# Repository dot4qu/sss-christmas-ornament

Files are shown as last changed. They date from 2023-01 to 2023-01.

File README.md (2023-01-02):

# sss-christmas-ornament

Photo of donut ornament on a christmas tree

A donut-shaped christmas ornament to share with friends and family in 2022. Hardware designed in KiCad, firmware written with Arduino framework and flashed over AVR UPDI interface.

More information in the writeup [here](https://brian.team/art/ornament-2022/).

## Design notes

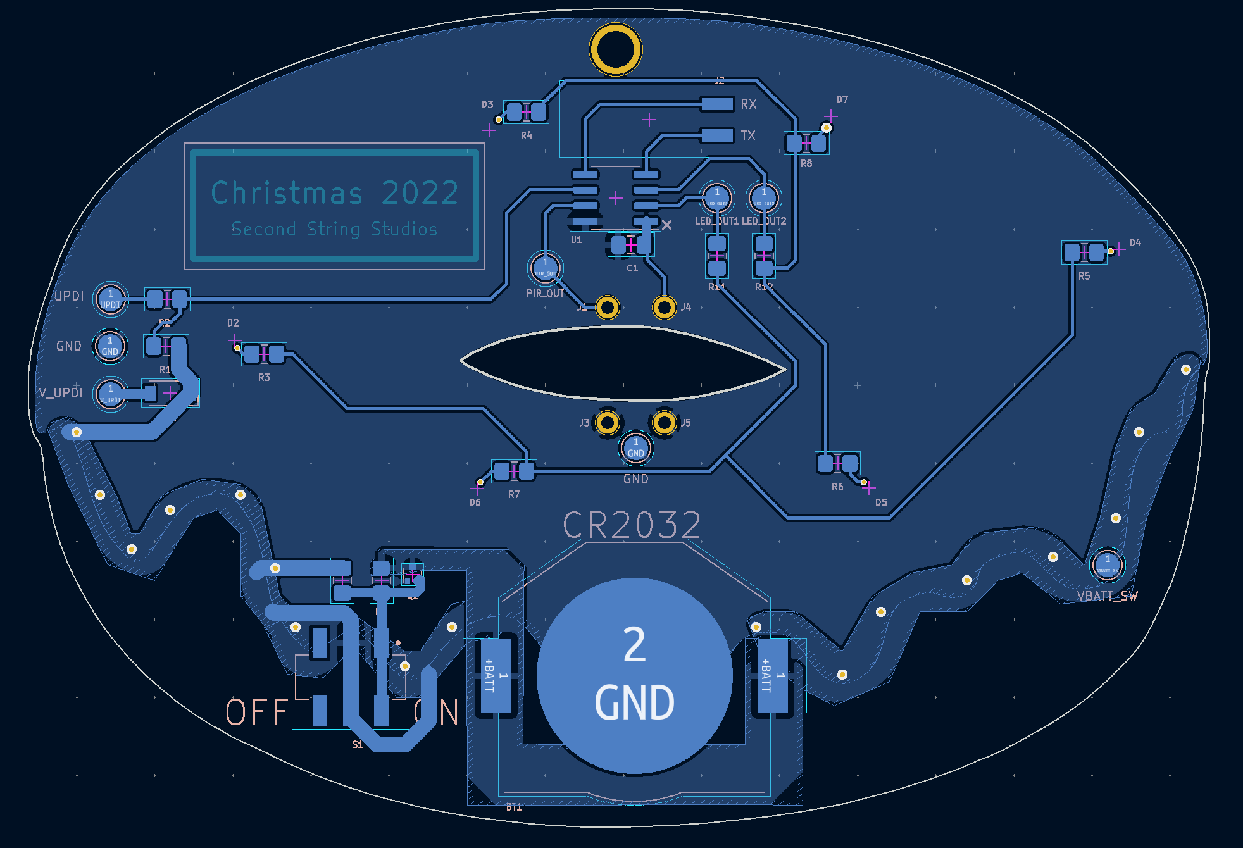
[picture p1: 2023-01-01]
sss_ornament_2022_pcb_back.png

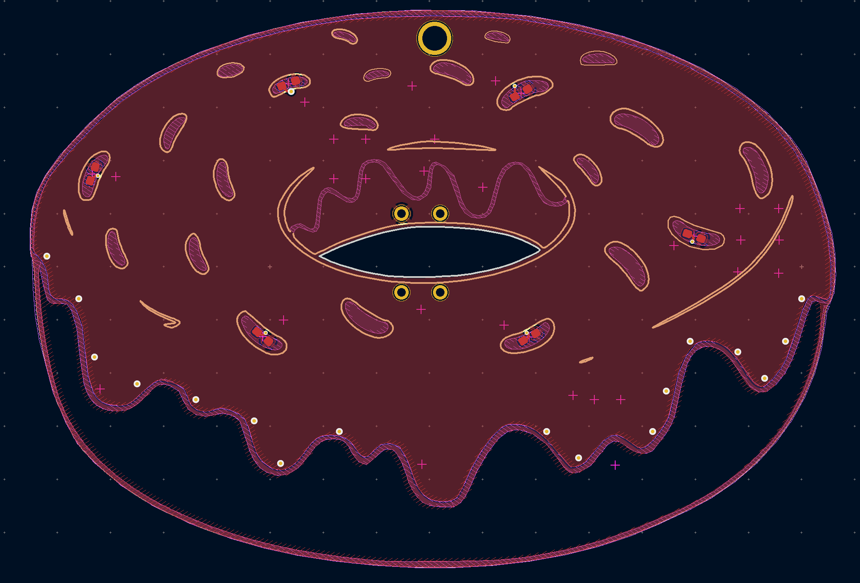
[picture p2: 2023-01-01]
sss_ornament_2022_pcb_front.png

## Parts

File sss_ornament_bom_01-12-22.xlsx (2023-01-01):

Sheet: sss_ornament_bom_edited
Designator | Package | Quantity | Designation | Supplier and ref
D7,D5,D2,D6,D4,D3 | LED_0603_1608Metric_Pad1.05x0.95mm_HandSolder | 6 | LED | https://www.digikey.de/en/products/detail/würth-elektronik/150060VS75000/4489906
R2 | R_0805_2012Metric_Pad1.20x1.40mm_HandSolder | 1 | 470 | https://www.digikey.de/en/products/detail/yageo/RC0805JR-07470RL/728333
R12,R11,R1,R9 | R_0805_2012Metric_Pad1.20x1.40mm_HandSolder | 4 | 0 | https://www.digikey.de/en/products/detail/stackpole-electronics-inc/RMCF0805ZT0R00/1756901
R8,R7,R6,R4,R3,R5 | R_0805_2012Metric_Pad1.20x1.40mm_HandSolder | 6 | 8.2k | https://www.digikey.de/en/products/detail/yageo/RC0805FR-078K2L/728147
R10 | R_0805_2012Metric_Pad1.20x1.40mm_HandSolder | 1 | 10k | https://www.digikey.de/en/products/detail/stackpole-electronics-inc/RNCP0805FTD10K0/2240262
C1 | C_0805_2012Metric_Pad1.18x1.45mm_HandSolder | 1 | 0.1uF | https://www.digikey.de/en/products/detail/samsung-electro-mechanics/CL21B104KBCNNNC/3886661
Q2 | SOT-723 | 1 | Q_PMOS_DGS | https://www.digikey.de/en/products/detail/toshiba-semiconductor-and-storage/SSM3J35AMFV-L3F/8543433
D1 | D_SOD-123 | 1 | 1N4148W | https://www.digikey.de/en/products/detail/smc-diode-solutions/1N4148W/6022450
U1 | SOIC-8_3.9x4.9mm_P1.27mm | 1 | ATtiny412-SS | https://www.digikey.de/en/products/detail/microchip-technology/ATTINY412-SSN/9947540
BT1 | BatteryHolder_AdamTech_BH-67D-5_1x2032 | 1 | CR2032 | https://www.digikey.de/en/products/detail/adam-tech/BH-67D-5/13537750
S1 | SW_JS202011SCQN | 1 | JS202011SCQN | https://www.digikey.de/en/products/detail/c-k/JS202011SCQN/2094299

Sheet: sss_ornament_bom_generated
Id | Designator | Package | Quantity | Designation | Supplier and ref
1 | D7,D5,D2,D6,D4,D3 | LED_0603_1608Metric_Pad1.05x0.95mm_HandSolder | 6 | LED
2 | R2 | R_0805_2012Metric_Pad1.20x1.40mm_HandSolder | 1 | 470
3 | J4 | PinHeader_1x01_P2.54mm_Vertical | 1 | V_PIR
4 | TP1 | TestPoint_Pad_D2.0mm | 1 | PIR_OUT
5 | TP6 | TestPoint_Pad_D2.0mm | 1 | V_UPDI
6 | J2 | Harwin_M20-89003xx_1x02_P2.54mm_Horizontal | 1 | Conn_01x02_Male
7 | R12,R11,R1,R9 | R_0805_2012Metric_Pad1.20x1.40mm_HandSolder | 4 | 0
8 | TP4 | TestPoint_Pad_D2.0mm | 1 | LED_OUT2
9 | R8,R7,R6,R4,R3,R5 | R_0805_2012Metric_Pad1.20x1.40mm_HandSolder | 6 | 8.2k
10 | J1 | PinHeader_1x01_P2.54mm_Vertical | 1 | Conn_01x01
11 | R10 | R_0805_2012Metric_Pad1.20x1.40mm_HandSolder | 1 | 10k
12 | TP3 | TestPoint_Pad_D2.0mm | 1 | LED_OUT1
13 | TP8,TP5 | TestPoint_Pad_D2.0mm | 2 | GND
14 | C1 | C_0805_2012Metric_Pad1.18x1.45mm_HandSolder | 1 | 0.1uF
15 | TP2 | TestPoint_Pad_D2.0mm | 1 | VBATT_SW
16 | TP7 | TestPoint_Pad_D2.0mm | 1 | UPDI
17 | Q2 | SOT-723 | 1 | Q_PMOS_DGS
18 | D1 | D_SOD-123 | 1 | 1N4148W
19 | J3 | PinHeader_1x01_P2.54mm_Vertical | 1 | GND
20 | J5 | PinHeader_1x01_P2.54mm_Vertical | 1 | PIR_TIME
21 | U1 | SOIC-8_3.9x4.9mm_P1.27mm | 1 | ATtiny412-SS
22 | BT1 | BatteryHolder_AdamTech_BH-67D-5_1x2032 | 1 | CR2032
23 | S1 | SW_JS202011SCQN | 1 | JS202011SCQN

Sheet: part tracking
name | part link | datasheet link
battery clip | https://www.digikey.de/en/products/detail/adam-tech/BH-67D-5/13537750 | https://app.adam-tech.com/products/download/data_sheet/196975/bh-67d-5-data-sheet.pdf
mini PIR | https://www.digikey.de/en/products/detail/adafruit-industries-llc/4667/13175529 | https://cdn-shop.adafruit.com/product-files/4667/4667_C15116.pdf | https://www.adafruit.com/product/4667#technical-details
slide switch | https://www.digikey.de/en/products/detail/c-k/JS202011SCQN/2094299 | https://www.ckswitches.com/media/1422/js.pdf
led fet |  | https://www.digikey.de/en/products/filter/transistors-fets-mosfets-arrays/289
rpp p fet | https://www.digikey.de/en/products/detail/toshiba-semiconductor-and-storage/SSM3J35AMFV-L3F/8543433
v updi diode | https://www.digikey.de/en/products/detail/smc-diode-solutions/1N4148W/6022450

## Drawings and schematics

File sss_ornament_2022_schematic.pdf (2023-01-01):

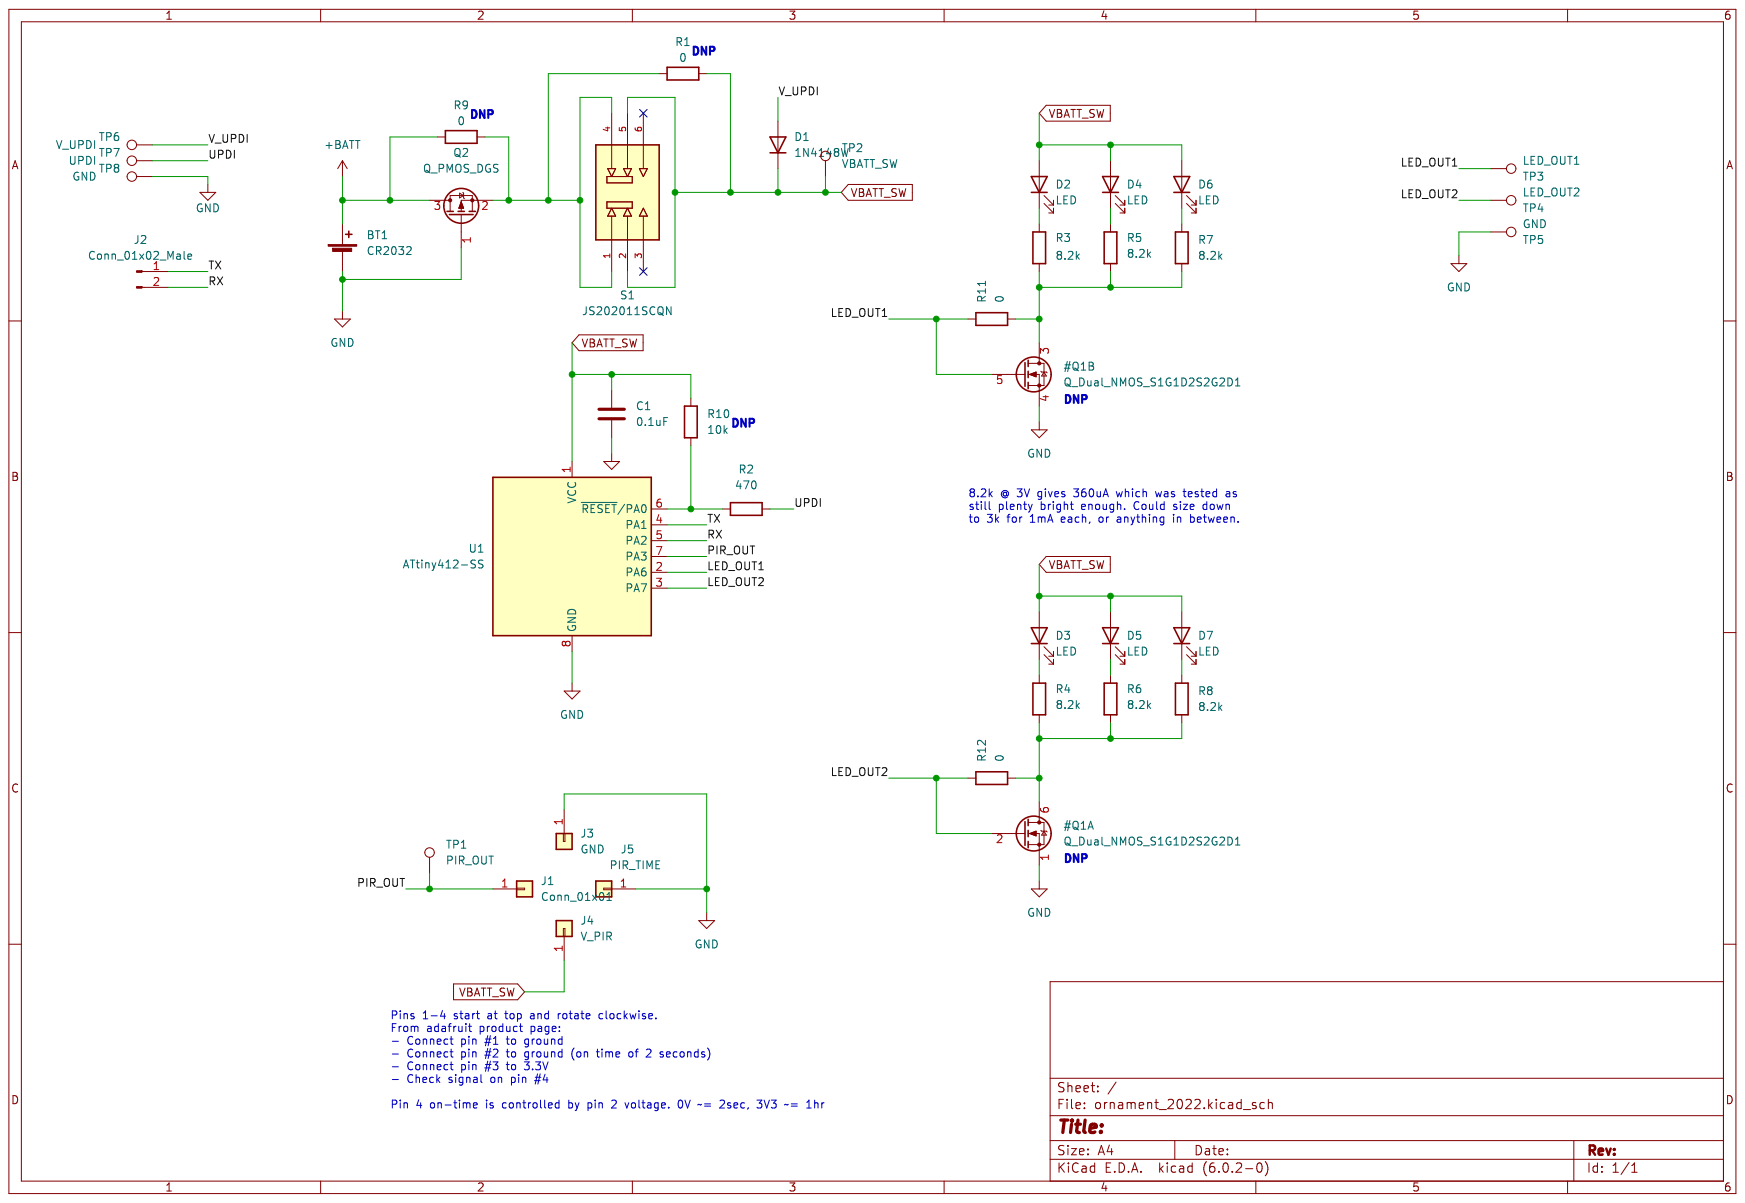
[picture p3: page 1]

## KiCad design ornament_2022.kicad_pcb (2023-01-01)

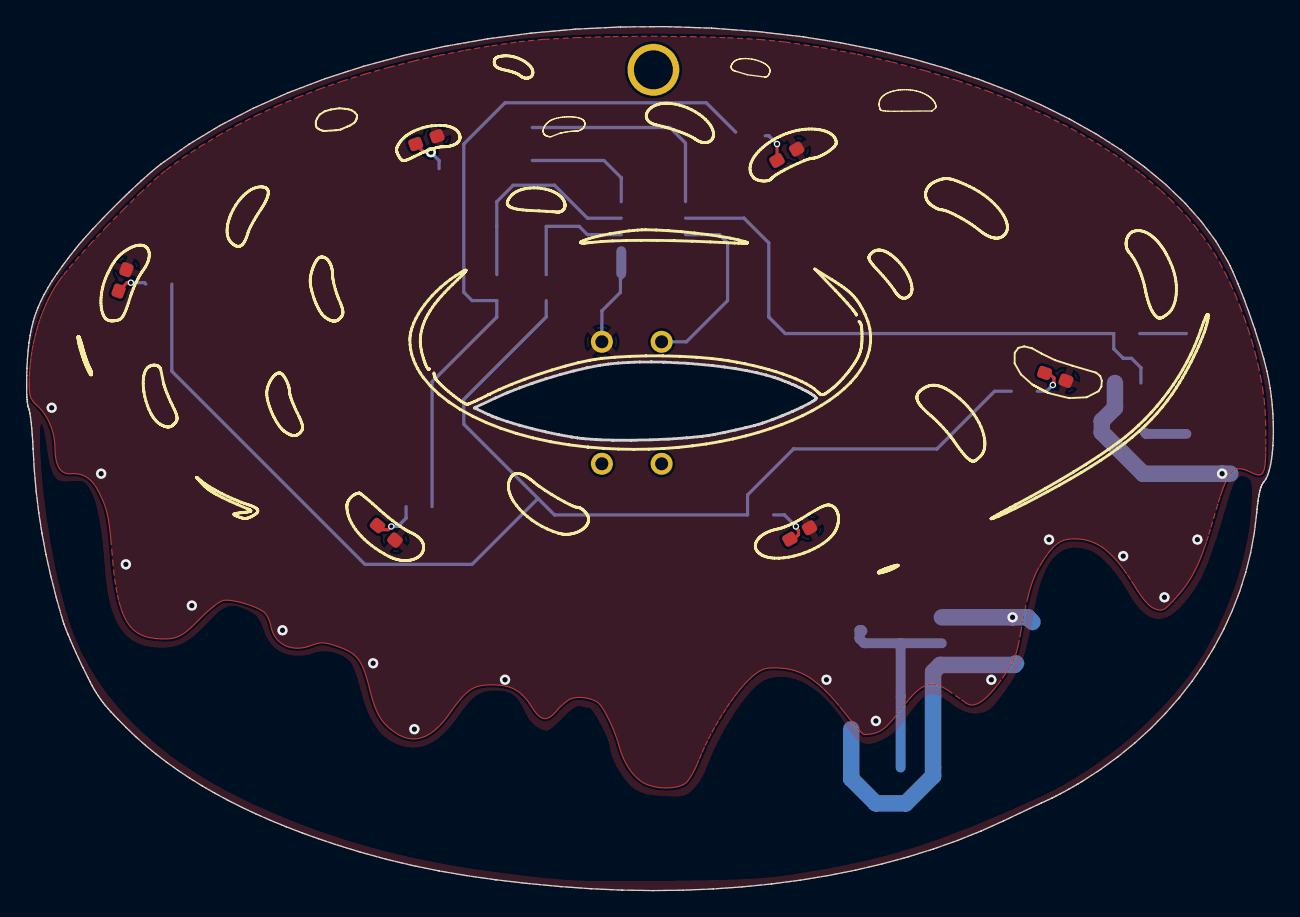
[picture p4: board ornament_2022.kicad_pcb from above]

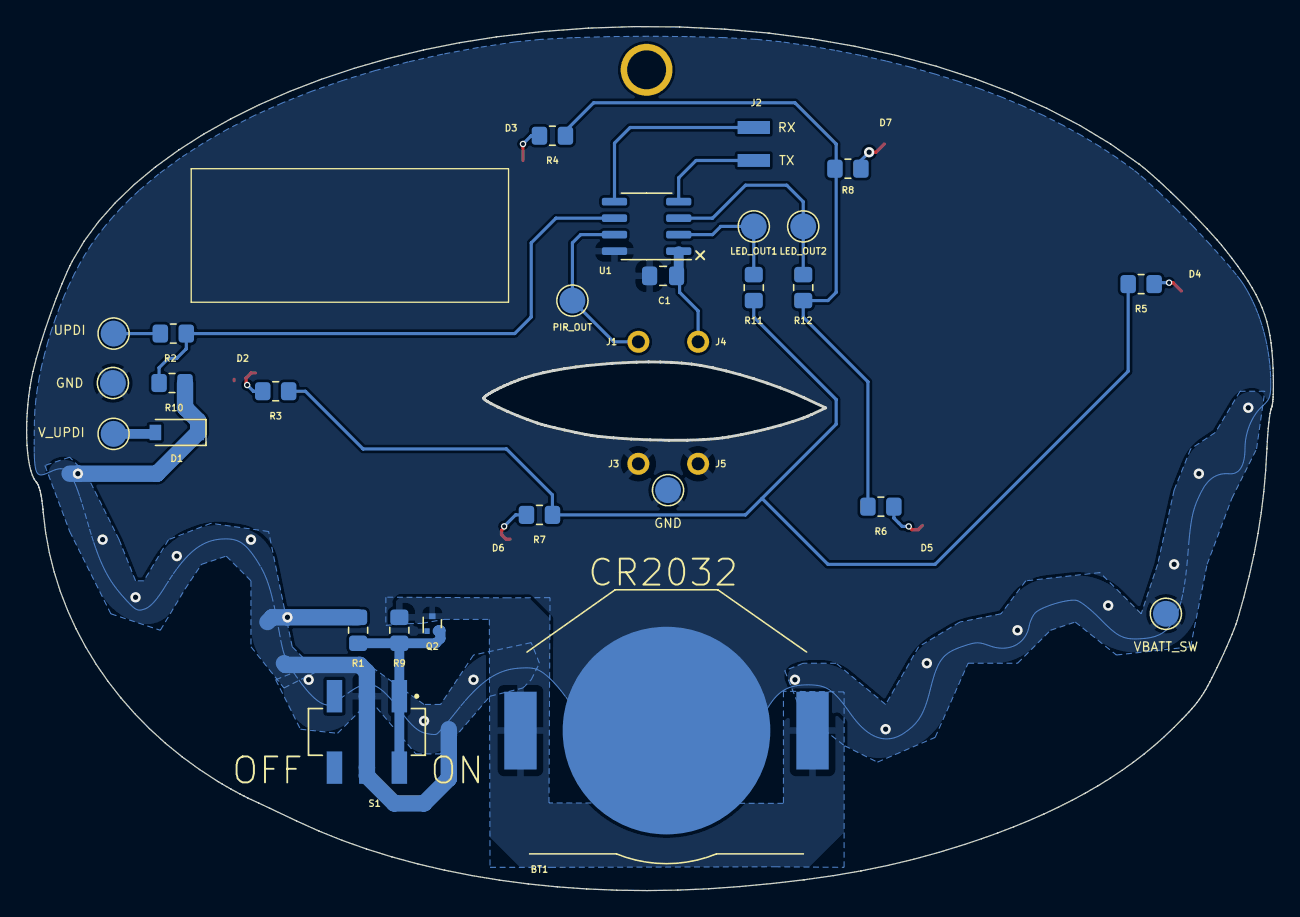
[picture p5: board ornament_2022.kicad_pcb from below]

Board: 2 copper layers, 96.1 x 66.6 mm, 37 parts (31 on the bottom side), 20 nets.

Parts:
BT1: CR2032; BatteryHolder_AdamTech_BH-67D-5_1x2032
C1: 0.1uF; C_0805_2012Metric_Pad1.18x1.45mm_HandSolder
D1: 1N4148W; D_SOD-123
D2, D3, D4, D5, D6, D7: LED; LED_0603_1608Metric_Pad1.05x0.95mm_HandSolder
J1: Conn_01x01; PinHeader_1x01_P2.54mm_Vertical
J2: Conn_01x02_Male; Harwin_M20-89003xx_1x02_P2.54mm_Horizontal
J3: GND; PinHeader_1x01_P2.54mm_Vertical
J4: V_PIR; PinHeader_1x01_P2.54mm_Vertical
J5: PIR_TIME; PinHeader_1x01_P2.54mm_Vertical
Q2: Q_PMOS_DGS; SOT-723
R1, R9, R11, R12: 0; R_0805_2012Metric_Pad1.20x1.40mm_HandSolder
R2: 470; R_0805_2012Metric_Pad1.20x1.40mm_HandSolder
R3, R4, R5, R6, R7, R8: 8.2k; R_0805_2012Metric_Pad1.20x1.40mm_HandSolder
R10: 10k; R_0805_2012Metric_Pad1.20x1.40mm_HandSolder
S1: JS202011SCQN; SW_JS202011SCQN
TP1: PIR_OUT; TestPoint_Pad_D2.0mm
TP2: VBATT_SW; TestPoint_Pad_D2.0mm
TP3: LED_OUT1; TestPoint_Pad_D2.0mm
TP4: LED_OUT2; TestPoint_Pad_D2.0mm
TP5, TP8: GND; TestPoint_Pad_D2.0mm
TP6: V_UPDI; TestPoint_Pad_D2.0mm
TP7: UPDI; TestPoint_Pad_D2.0mm
U1: ATtiny412-SS; SOIC-8_3.9x4.9mm_P1.27mm

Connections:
+BATT: BT1.1 (+), Q2.3 (D), R9.1
/LED_OUT1: R11.1, TP3.1, U1.2 (PA6)
/LED_OUT2: R12.1, TP4.1, U1.3 (PA7)
/PIR_OUT: J1.1, TP1.1, U1.7 (PA3)
/RX: J2.2, U1.5 (PA2)
/TX: J2.1, U1.4 (PA1)
/UPDI: R2.2, TP7.1
/V_UPDI: D1.2 (A), TP6.1
GND: BT1.2 (-), C1.2, J3.1, J5.1, Q2.1 (G), TP5.1, TP8.1, U1.8 (GND)
unnamed: D2.1 (K), R3.1
unnamed: D3.1 (K), R4.1
unnamed: D4.1 (K), R5.1
unnamed: D5.1 (K), R6.1
unnamed: D6.1 (K), R7.1
unnamed: D7.1 (K), R8.1
unnamed: Q2.2 (S), R1.1, R9.2, S1.1, S1.4
unnamed: R2.1, R10.1, U1.6 (~RESET/PA0)
unnamed: R3.2, R5.2, R7.2, R11.2
unnamed: R4.2, R6.2, R8.2, R12.2
VBATT_SW: C1.1, D1.1 (K), D2.2 (A), D3.2 (A), D4.2 (A), D5.2 (A), D6.2 (A), D7.2 (A), J4.1, R1.2, R10.2, S1.2, S1.5, TP2.1, U1.1 (VCC)

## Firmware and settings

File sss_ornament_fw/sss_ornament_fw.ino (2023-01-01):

#include <avr/sleep.h>

#define LED0_OUT PIN_PA6
#define LED1_OUT PIN_PA7
#define PIR_IN PIN_PA3

#define SLEEP_TIMEOUT_MIN (30)
#define SLEEP_TIMEOUT_MS (1000UL * 60 * SLEEP_TIMEOUT_MIN)

#define LAST_DISPLAYED_MODE_EEPROM_ADDR (0x00)

enum led_mode_t {
  LED_MODE_ALTERNATE_FLASH = 0x00,
  LED_MODE_ALTERNATE_FADE,
  LED_MODE_TRIPLE_FLASH,
  LED_MODE_COUNT,
};

bool success;
volatile uint32_t start_ms;
led_mode_t mode;
uint8_t triple_flash_pin;

#if F_CPU != 1000000
#error Must burn bootloader for 1MHz operation!
#endif

uint16_t normalized_fade_values[101];

ISR(PORTA_PORT_vect) {
  PORTA.INTFLAGS = 0xFF;

  // Refresh start time every time PIR triggers. millis doesn't increment in an ISR but we don't
  // care, just refresh to the most recent time. It's also fast enough and ISR safe to do here.
  start_ms = millis();
}

//EMPTY_INTERRUPT(PORTA_PORT_vect);

void gpio_set(uint8_t pin) {
  digitalWrite(pin, HIGH);
//  if (pin == LED0_OUT) {
//    TCD0.CTRLD &= ~TCD_CMPAVAL_gm;
//  } else if (pin == LED1_OUT) {
//    TCD0.CTRLD &= ~TCD_CMPBVAL_gm;
//  }  
}

void gpio_clr(uint8_t pin) {
  digitalWrite(pin, LOW);
//if (pin == LED0_OUT) {
//    TCD0.CTRLD |= TCD_CMPAVAL_gm;
//  } else if (pin == LED1_OUT) {
//    TCD0.CTRLD |= TCD_CMPBVAL_gm;
//  }
}

void gpio_toggle(uint8_t pin) {
  digitalWrite(pin, !digitalRead(pin));
//  if (pin == LED0_OUT) {
//    TCD0.CTRLD ^= TCD_CMPAVAL_gm;
//  } else if (pin == LED1_OUT) {
//    TCD0.CTRLD ^= TCD_CMPBVAL_gm;
//  }
}

void pwm_timer_init(void) {
    // Enable-protected reg must have 0 written to enable bit before any other bits can be changed, and it defaults to
    // enabled on startup
    TCD0.CTRLA &= ~TCD_ENABLE_bm;

    // Don't need overlapping PWM signals so just do oneramp
    TCD0.CTRLB = TCD_WGMODE_ONERAMP_gc;

    // Disable all input control
    TCD0.INPUTCTRLA = TCD_INPUTMODE_NONE_gc;
    TCD0.INPUTCTRLB = TCD_INPUTMODE_NONE_gc;

    // We will always start high with A output and end high with B output. The clear for A and
    // set for B values are what are adjusted based on desired duty cycle. EVERYTHING is cleared at CMPBCLR, therefore
    // you can't have both pwm signals start at 0 and end at arbitrary times. You have to offset B so it's pwm
    // cycle always ends at 0xFFF, then adjust the start time. That way you can overlap outputs all the way to
    // CMPASET=0,CMPACLR=0xFFE and CMPBSET=0x1,CMPBCLR=0xFFF.
    TCD0.CMPASET = 0x000;
    TCD0.CMPBCLR = 0xFFF;

    TCD0.CMPACLR = 0x000;
    TCD0.CMPBSET = 0x801;
    // System 20mhz clock w/ largest prescaler possible of 32 but no synchronization prescaler. Must be done as last
    // operation before starting timer with ENABLE bit
    // NOTE :: DEFAULT TIMER FOR MILLIS/MICROS FUNCTIONS ON 1-SERIES ATTINIES IS TCD. YOU MUST CHANGE THIS TO TCB IN
    // ARDUINO PORT SETTINGS
    TCD0.CTRLA = TCD_CLKSEL_SYSCLK_gc | TCD_CNTPRES_DIV4_gc | TCD_SYNCPRES_DIV1_gc;
}

void pwm_timer_start(void) {
  TCD0.CTRLC &= ~TCD_CMPOVR_bm;
    
  // Enable WOA and WOB (don't need C and D). Since FAULTCTRL reg is write protected we need to make it editable in
  // CCP reg. Must be done in start func because we can't take over output pins in stop func unless we disable them in FAULTCTRL.
  CPU_CCP        = CCP_IOREG_gc;
  TCD0.FAULTCTRL = TCD_CMPAEN_bm | TCD_CMPBEN_bm;
  
  while (!(TCD0.STATUS & TCD_ENRDY_bm)) {
      ;
  }

  TCD0.CTRLA |= TCD_ENABLE_bm;
}

void pwm_timer_stop(void) {
//  // Enable-protected reg must have 0 written to enable bit before any other bits can be changed,
//  // apparently for the FULL TCD0 reg set (including FAULTCTRL below);
//  TCD0.CTRLA &= ~TCD_ENABLE_bm;
//    
//  // Must disable the WOA/B outputs as well, otherwise we can't write to them still
//  CPU_CCP        = CCP_IOREG_gc;
//  TCD0.FAULTCTRL &= ~TCD_CMPAEN_bm;
////  CPU_CCP        = CCP_IOREG_gc;
////  TCD0.FAULTCTRL &= ~TCD_CMPBEN_bm;

//  TCD0.CTRLA &= ~TCD_ENABLE_bm;
  
  TCD0.CTRLC |= TCD_CMPOVR_bm;
}

void pwm_timer_sync(void) {
    TCD0.CTRLE = TCD_SYNCEOC_bm;
}

bool set_pwm_duty_cycle(uint8_t led_group, uint8_t duty_cycle) {
  if (led_group != LED0_OUT && led_group != LED1_OUT) {
    return false;
  }
  
  if (duty_cycle > 100) {
    return false;
  }

  if (led_group == LED0_OUT) {
    TCD0.CMPACLR = normalized_fade_values[duty_cycle];
  } else if (led_group == LED1_OUT) {
    TCD0.CMPBSET = 0xFFF - normalized_fade_values[duty_cycle];
  }

  return true;
}

void deep_sleep() {
  // Turn off all LEDs before sleeping
  gpio_set(LED0_OUT);
  gpio_set(LED1_OUT);
  
  sleep_enable();
  set_sleep_mode(SLEEP_MODE_STANDBY);
  sleep_cpu();

  // Disable once (if) we wake back up and refresh sleep timer
  start_ms = millis();
  sleep_disable();
}

void eeprom_get_byte(uint8_t eeprom_byte_offset, uint8_t *val) {
  memcpy(val, (uint8_t *)(EEPROM_START + eeprom_byte_offset), 1);
}

void eeprom_save_byte(uint8_t eeprom_byte_offset, uint8_t val) {
  while (NVMCTRL.STATUS & NVMCTRL_EEBUSY_bm);
    
  NVMCTRL.ADDR = EEPROM_START;
    
  *(uint8_t *)(EEPROM_START + eeprom_byte_offset) = val;
  
  CPU_CCP = CCP_SPM_gc;
  NVMCTRL.CTRLA = NVMCTRL_CMD_PAGEERASEWRITE_gc;
}

void setup(){
  success = false;
  
  pinMode(LED0_OUT, OUTPUT);
  pinMode(LED1_OUT, OUTPUT);

  uint8_t last_displayed_mode = 0x00;
  eeprom_get_byte(LAST_DISPLAYED_MODE_EEPROM_ADDR, &last_displayed_mode);

  // Increment last displayed and set mode, resetting to zero if we were on last mode. Default eeprom state of 0xFF also
  // handled by increment automatically rolling over to 0x00. Save for next boot, then continue normal operation
  last_displayed_mode++;
  if (last_displayed_mode >= LED_MODE_COUNT) {
    mode = (led_mode_t)0x00;
  } else {
    mode = (led_mode_t)last_displayed_mode;
  }
  eeprom_save_byte(LAST_DISPLAYED_MODE_EEPROM_ADDR, mode);

  // Startup sequence to differentiate reboot
  for (int i = 0; i < 8; i++) {
      digitalWrite(LED0_OUT, HIGH);
      digitalWrite(LED1_OUT, HIGH);
      delay(100);
      digitalWrite(LED0_OUT, LOW);
      digitalWrite(LED1_OUT, LOW);
      delay(100);
  }
  delay(500);

  if (mode == LED_MODE_ALTERNATE_FADE) {
    // Mapping 1-99 directly to 1-4094 for PWM duty value is very skewed w/ human eye towards brighter, so fade
    // is quick drop to zero then seemingly a long full bright time. The mapping ratio of 1 count on former scale
    // to 10-bit scale is ~41, so slowly scale the incremement value each time by the index / 2. Once incremement
    // value reaches standard mapped step of 41, just keep it there for the remaining normalized values.
    float mult = 0.5;
    int normalized_val;
    int factor;
    for (int i = 1; i < 99; i++) {
      factor = (int)(i * mult);
      if (factor < 41) {
        normalized_val = i * factor;
      } else {
        normalized_val = i * 41;
      }
  
      // Store 0xFFF - val because we need to invert pwm logic for low side driver
      normalized_fade_values[i] = 0xFFF - normalized_val;
    }
  
    normalized_fade_values[0] = 0xFFF;
    normalized_fade_values[100] = 0x000;
    
    pwm_timer_init();  
    pwm_timer_start();
  } else if (mode == LED_MODE_TRIPLE_FLASH) {
    triple_flash_pin = LED0_OUT;
  }
  
  // Set up interrupt on PIR pin. Must be BOTHEDGES or LEVEL since we're using a partially-async pin. If using PA2
  // or PA6 (fully async), can wake from deep sleep with any trigger.
  PORTA.PIN3CTRL = (PORTA.PIN3CTRL & ~PORT_ISC_gm) | PORT_ISC_BOTHEDGES_gc | PORT_PULLUPEN_bm;
  
  sei();
  
  start_ms = millis();
}

void loop() {
  // If we've reached timeout with nothing, that means either no movement or constant movement for the timeout period.
  // If the PIR pin is still high, that means it's continuously reported movement, so just refresh the timeout time. If
  // it's low, then the timeout has actually elapsed with no trigger, so sleep.
  if ((millis() - start_ms) > SLEEP_TIMEOUT_MS) {
    if (digitalRead(PIR_IN) == LOW) {
      deep_sleep();
    } else {
      start_ms = millis();
    }
  }
  
  switch (mode) {
    case LED_MODE_ALTERNATE_FLASH:
      gpio_toggle(LED0_OUT);
      gpio_toggle(LED1_OUT);
      delay(1000);
      break;
    case LED_MODE_ALTERNATE_FADE:
      pwm_timer_start();
      for (int i = 0; i <= 100; i += 1) {
        success = set_pwm_duty_cycle(LED0_OUT, i);
        (void)success;
        success = set_pwm_duty_cycle(LED1_OUT, 100 - i);
        (void)success;
      
        pwm_timer_sync();
        delay(10);
      }
      
      for (int i = 100; i >= 0; i-=1) {
        success = set_pwm_duty_cycle(LED0_OUT, i);
        (void)success;
        success = set_pwm_duty_cycle(LED1_OUT, 100 - i);
        (void)success;
      
        pwm_timer_sync();
        delay(10);
      }
      break;
    case LED_MODE_TRIPLE_FLASH:
      for (int i = 0; i < 6; i++) {
        gpio_toggle(triple_flash_pin);
        delay(300);
      }
      
      gpio_set(triple_flash_pin);
      delay(300);

      triple_flash_pin = triple_flash_pin == LED0_OUT ? LED1_OUT : LED0_OUT;
      break;
    default:
      mode = LED_MODE_ALTERNATE_FADE;
      break;
  }
}
